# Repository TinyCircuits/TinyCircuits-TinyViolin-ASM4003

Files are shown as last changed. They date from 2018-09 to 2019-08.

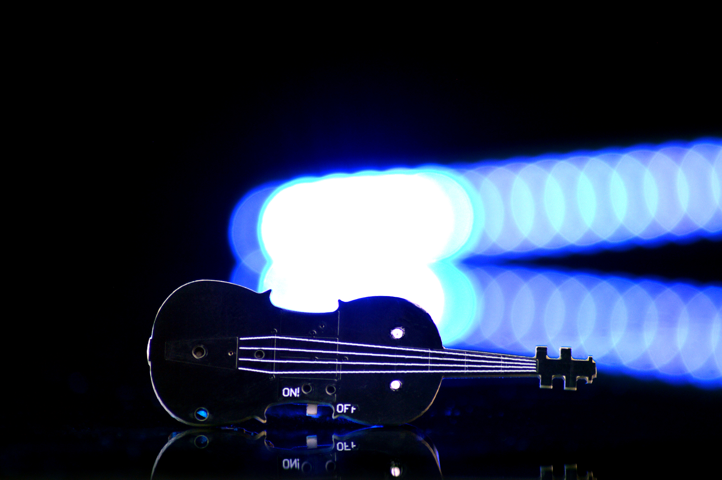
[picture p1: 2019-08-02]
images/ASM4003-Tutorial-Image-01.jpg

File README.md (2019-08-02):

# TinyCircuits TinyViolin
# ASM4003 Rev1

The design files are located under design_files/ for the TinyCircuits ASM4003 Rev 1 PCB.  This is a Tiny Violin with capacitive touch sensors and a buzzer.

Format is in Cadsoft Eagle format - Eagle version 6.2 was used for the original design.

For more infomation on this, check out the product page at TinyCircuits.com:  https://tinycircuits.com/collections/kits/products/tiny-violin

# License:

Design by TinyCircuits.
All design files are released under the Creative Commons Attribution Share-Alike 3.0 License, see the following link for details: http://creativecommons.org/licenses/by-sa/3.0

All text above must be included in any redistribution or derived design

This project uses designs and concepts developed as part of the Arduino project and the LilyPad project.  The TinyCircuits design files themselves (schematics, PCB and libraries) are not directly derived from these works' design files and have been created new, however the concepts and basic architecture behind the TinyDuino and TinyLily products are derived and we thank the hard work of the organizations below for their contributions to open-source hardware:
  
Original Arduino Uno Design by Team Arduino

LilyPad Arduino Design by Leah Buechley and Sparkfun Electronics

Please support the open-source hardware community

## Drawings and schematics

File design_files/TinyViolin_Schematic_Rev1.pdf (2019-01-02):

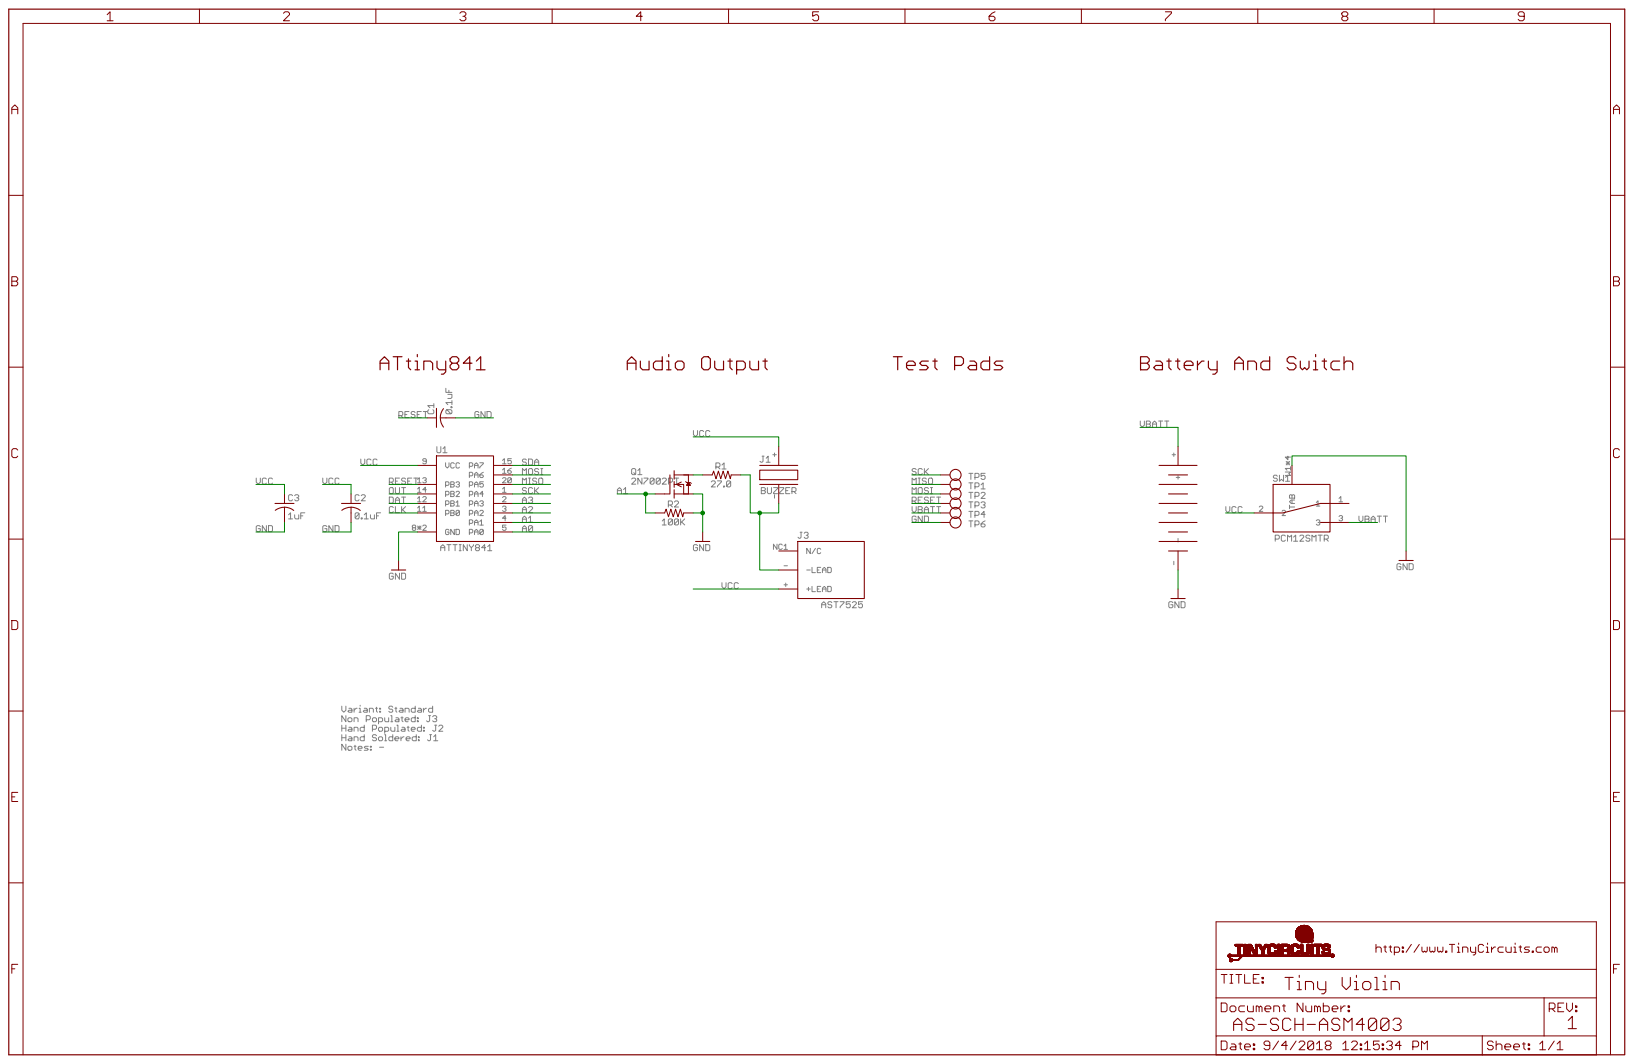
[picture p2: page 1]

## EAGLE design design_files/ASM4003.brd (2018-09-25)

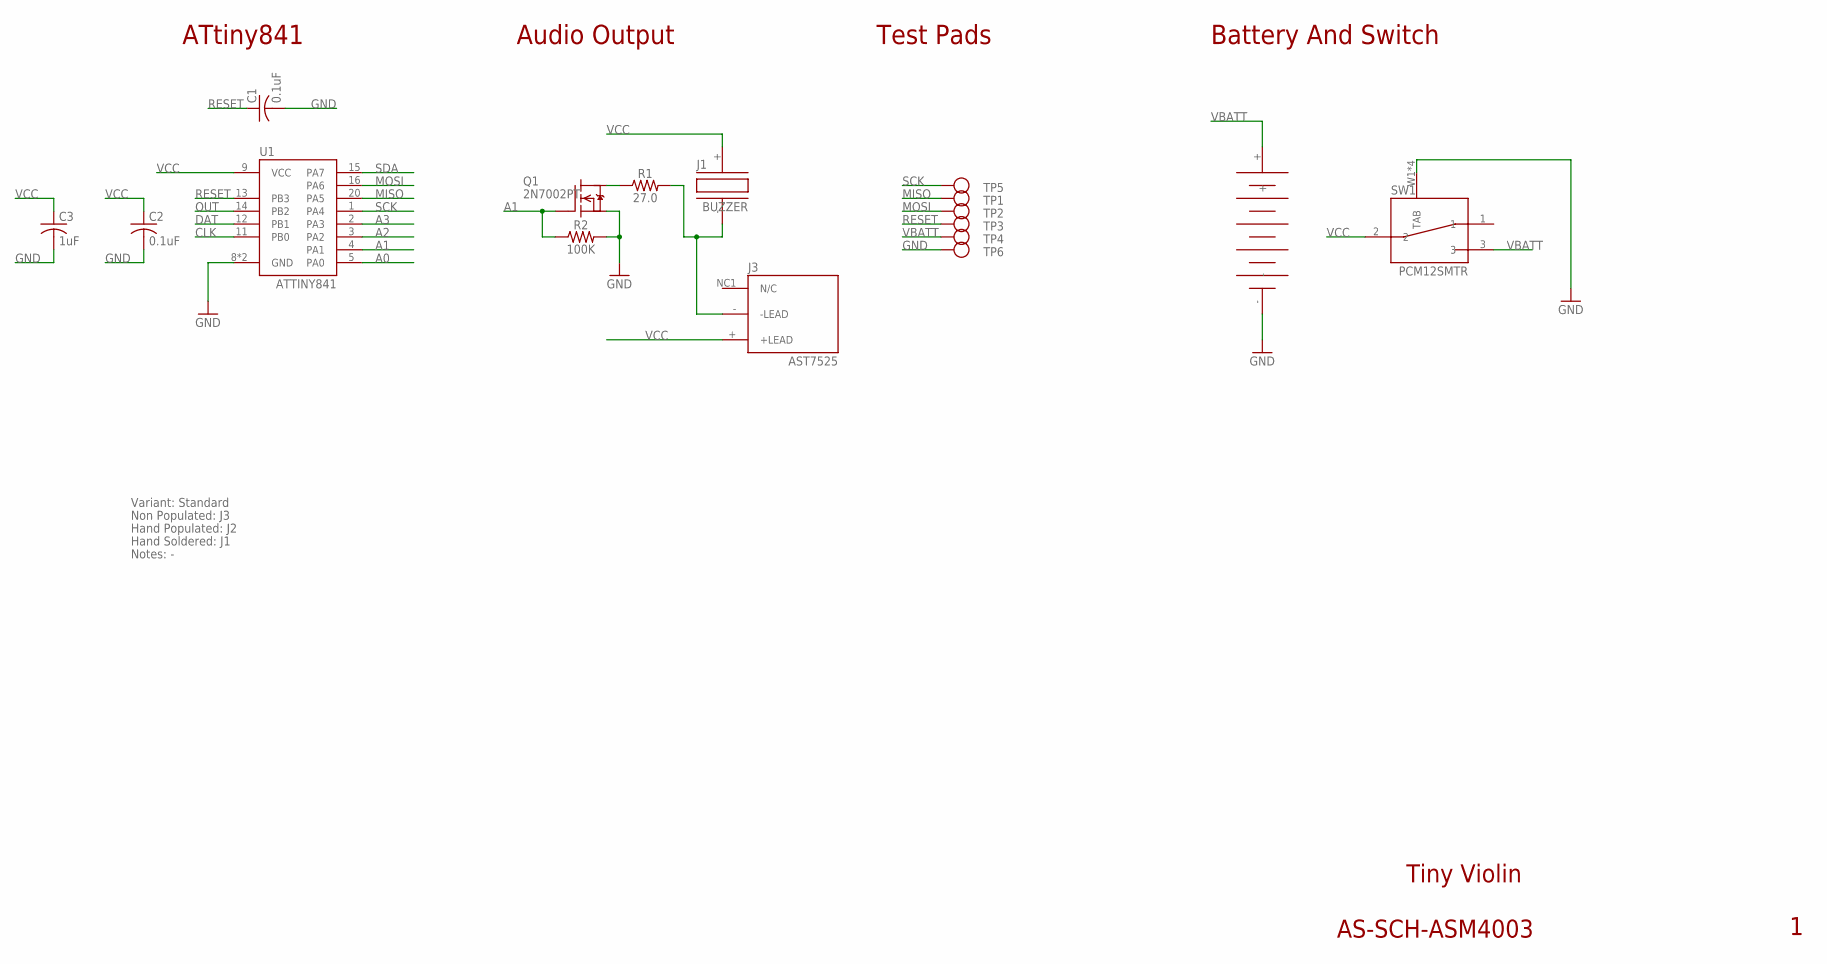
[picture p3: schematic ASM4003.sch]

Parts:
C1: 0.1uF; C0402; PARTNO AS-ITM-00008
C2: 0.1uF; C0402
C3: 1uF; C0402
J1: BUZZER; BUZZER_12MM
J2: 1225; COIN_1220_SMD; PARTNO AS-ITM-00468
J3: AST7525
Q1: 2N7002PT; SOT-416
R1: 27.0; 0402
R2: 100K; 0402
SW1: PCM12SMTR; PARTNO AS-ITM-00469
TP1, TP2, TP3, TP4, TP5, TP6: TEST_POINT; TEST_POINT_1MM
U1: ATTINY841; VQFN-20

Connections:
A0: U1.5 (PA0)
A1: Q1.1 (G), R2.1, U1.4 (PA1)
A2: U1.3 (PA2)
A3: U1.2 (PA3)
CLK: U1.11 (PB0)
DAT: U1.12 (PB1)
GND: C1.2, C2.2, C3.2, J2.-, Q1.2 (S), R2.2, SW1.W1 (TAB), SW1.W2 (TAB), SW1.W3 (TAB), SW1.W4 (TAB), TP6.P$1, U1.8 (GND), U1.PAD (GND)
MISO: TP1.P$1, U1.20 (PA5)
MOSI: TP2.P$1, U1.16 (PA6)
unnamed: Q1.3 (D), R1.1
unnamed: J1.- (2), J3.- (-LEAD), R1.2
OUT: U1.14 (PB2)
RESET: C1.1, TP3.P$1, U1.13 (PB3)
SCK: TP5.P$1, U1.1 (PA4)
SDA: U1.15 (PA7)
VBATT: J2.+, SW1.3, TP4.P$1
VCC: C2.1, C3.1, J1.+ (1), J3.+ (+LEAD), SW1.2, U1.9 (VCC)

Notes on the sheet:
Tiny Violin
AS-SCH-ASM4003
Test Pads
ATtiny841
Battery And Switch
Audio Output
Variant: Standard
Non Populated: J3
Hand Populated: J2
Hand Soldered: J1
Notes: -

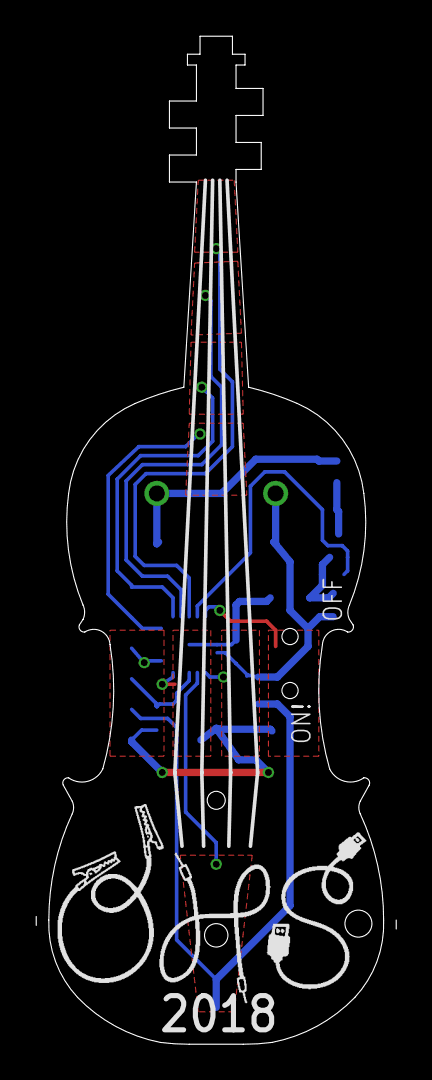
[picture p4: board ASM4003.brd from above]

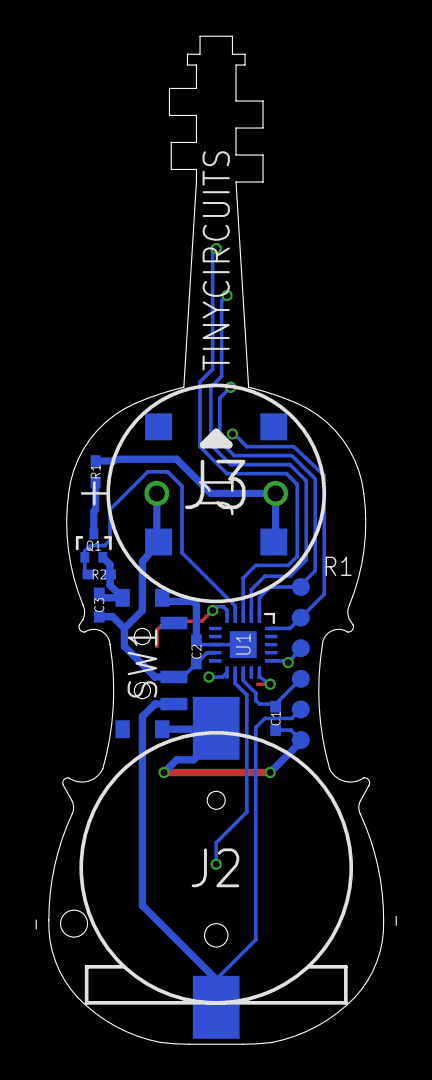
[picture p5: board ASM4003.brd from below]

Board: 2 copper layers, 20.0 x 56.0 mm, 18 parts (17 on the bottom side), 10 nets.

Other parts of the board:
U$1: DOCFIELD-TINYCIRCUITS-PCB

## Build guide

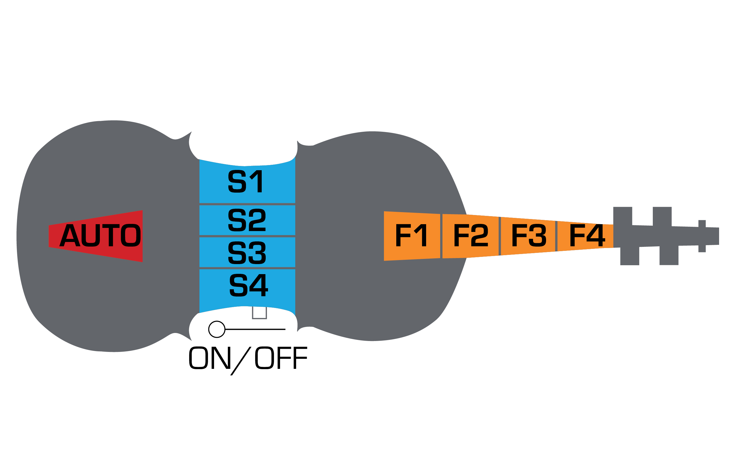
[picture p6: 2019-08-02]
images/ASM4003-Tutorial-Image-02.jpg

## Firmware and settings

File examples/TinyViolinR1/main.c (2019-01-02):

#include <inttypes.h>
#include <avr/io.h>
#include <avr/interrupt.h>
#include <util/delay.h>
#include <avr/sleep.h>
#include <avr/pgmspace.h>

#define true 1
#define false 0

int main(void);
unsigned int getCapReading(uint8_t pin);
unsigned int capRead(uint8_t pin);


uint8_t counter = 0;
uint8_t countMax = 30;
uint8_t buttonPressed = 0;
uint16_t capThresh = 535;

#define numCapChannels 9
int capTouchCal[numCapChannels];
int capTouchCurrent[numCapChannels];
int overCalCount[numCapChannels];
void play_RTTTL(const char* p);

unsigned long avg;
const int amtAvg = 5;
int avgBuf[5];
int avgPos = 0;

#include "pitches.h"
#include "songs.h"

uint16_t notesAll[7*5]={NOTE_C3,NOTE_D3,NOTE_E3,NOTE_F3,NOTE_G3,NOTE_A3, NOTE_B3,
                   NOTE_C4,NOTE_D4,NOTE_E4,NOTE_FS4,NOTE_G4,NOTE_A4, NOTE_B4,
                   NOTE_C5,NOTE_D5,NOTE_E5,NOTE_FS5,NOTE_G5,NOTE_A5, NOTE_B5,
                   NOTE_C6,NOTE_D6,NOTE_E6,NOTE_FS6,NOTE_G6,NOTE_A6, NOTE_B6,
                   NOTE_C7,NOTE_D7,NOTE_E7,NOTE_F7,NOTE_G7,NOTE_A7, NOTE_B7};

int maxReading = 0;
int primary = 0;
    
void updateCapTouch(){
    maxReading = 0;
    primary = 0;
    int j;
    for (j = 0; j < numCapChannels; j++) {
    int val = getCapReading(j);
    if (val < capTouchCal[j]) {
      capTouchCal[j] = val;
    } else if (val > capTouchCal[j] + 1) {
      overCalCount[j]++;
      if (overCalCount[j] > 3) {
        overCalCount[j] = 0;
        capTouchCal[j] += 1;
      } else {
        //overCalCount[j]=0;
      }
      
      if (j<9 && capTouchCurrent[j] > maxReading) {
        maxReading = capTouchCurrent[j];
        primary = j;
      }
    }
    capTouchCurrent[j] = val  - capTouchCal[j];
  }
}
int main(void) {
  int biggestMagnitude = 0;
  int isTouch = 0;
  int initialTouchPos = 0;
  int finalTouchPos = 0;
  int currentTouchedPositions = 0;

  CCP = 0xD8;
  CLKPR = 0;

  
  DDRA=(1<<1);
  ADCSRA = _BV(ADEN) | 4 | 1;//250KHz clock

  int pin, i, j;
  for (pin = 0; pin < numCapChannels; pin++) {
    capTouchCal[pin] = 1000;//getCapReading(pin);
    overCalCount[pin] = 0;
  }
  
  TOCPMSA0 = _BV(TOCC0S1);
  TCCR2A = _BV(COM2A1)|_BV(COM2B1)|_BV(WGM21);
  TCCR2B = _BV(WGM23)|_BV(WGM22)|_BV(CS20);
  //TIFR2 = _BV(TOV2);
  //31250
  uint8_t pulseWidth=128;
  
  ICR2 = 255-1;
  
    if(pulseWidth){
      OCR2B=pulseWidth-1;
      TOCPMCOE|=((1<<TOCC0OE));
    }else{
      TOCPMCOE&=~((1<<TOCC0OE));
      OCR2B=0;
    }
    
  
  while (1)
  {
    _delay_ms(10);
  
    updateCapTouch();
    
    int ledToLight = primary*3;
    if (primary < 5)
      ledToLight += (capTouchCurrent[primary + 1] / (maxReading/2));
    if (primary > 0)
      ledToLight -= (capTouchCurrent[primary - 1] / (maxReading/2));
      
    int completedTouch = 0;
    int onSwipe = 0;
    int offSwipe = 0;
      
    uint16_t tone=0;
    
    int s1=capTouchCurrent[5];int s1v=30;
    int s2=capTouchCurrent[6];int s2v=85;
    int s3=capTouchCurrent[7];int s3v=12;
    int s4=capTouchCurrent[0];int s4v=40;
      
    if(s1>s1v && s1-s1v>s2-s2v){
      tone=4;
    }
    if(s4>s4v && s4-s4v>s3-s3v){
      tone=14+2;
    }
    if(s3>s3v && s3-s3v>=s2-s2v){// s3-s3v>=s4-s4v && 
      tone=7+5;
    }
    if(s2>s2v && s2-s2v>=s3-s3v){// && s2-s2v>=s1-s1v
      tone=7+1;
    }
    
    if(tone){
      if(capTouchCurrent[4]>100 && capTouchCurrent[3]>110/2){
        tone+=4;
      }
      else if(capTouchCurrent[3]>110){
        tone+=3;
      }
      else if(capTouchCurrent[2]>110){
        tone+=2;
      }
      else if(capTouchCurrent[1]>100){
        tone+=1;
      }
    }
    if(!tone){
      if(capTouchCurrent[8]>150){
        TOCPMCOE|=((1<<TOCC0OE));
          
          unsigned int rand=0;
          for (j = 0; j < numCapChannels; j++) {
            rand+=capTouchCurrent[j]+capTouchCal[j];
          }
          while(rand>9)rand-=9;
          if(rand==0){
            play_RTTTL(song_0);
          }else if(rand==1){
            play_RTTTL(song_1);
          }else if(rand==2){
            play_RTTTL(song_2);
          }else if(rand==3){
            play_RTTTL(song_3);
          }else if(rand==4){
            play_RTTTL(song_4);
          }else if(rand==5){
            play_RTTTL(song_5);
          }else if(rand==6){
            play_RTTTL(song_6);
          }else if(rand==7){
            play_RTTTL(song_7);
          }else if(rand==8){
            play_RTTTL(song_8);
          }else if(rand==9){
            play_RTTTL(song_9);
          }
      }
    }
    if(tone){
      tone=8000000ul/(unsigned long)notesAll[tone];
      if(ICR2!=tone){
        ICR2=tone;
        OCR2B=tone/2;
        TOCPMCOE|=((1<<TOCC0OE));
        }
      if (!isTouch) {
        isTouch = 1;
        initialTouchPos = primary;
        finalTouchPos = primary;
        currentTouchedPositions=0;
      } else {
        finalTouchPos = primary;
        for (j = 0; j < 6; j++) {
          if(capTouchCurrent[j]>10)
            currentTouchedPositions|=(1<<j);
         }
      }
    } /*else {
      if (isTouch) {
        isTouch = 0;
        completedTouch = 1;
      }
    }*/else{
      if(ICR2!=0){
        TOCPMCOE&=~((1<<TOCC0OE));
        ICR2=0;
        PORTA=0;
        }
    }
    
  }
  return 0;
}

unsigned int getCapReading(uint8_t pin) {
  unsigned int i, avg=0;
  for (i = 0; i < 10; i++) {
    avg += capRead(pin);
  }
  avg /= 10;
  return avg;
}

unsigned int capRead(uint8_t pin) {
  while(PINA&(1<<1));
  _delay_us(1);
  if(pin>0)pin+=1;
  
  if(pin==8){
    pin=11;
    PUEB |= (1 << (0)); //charge external cap
  }else if(pin==9){
    pin=10;
    PUEB |= (1 << (1)); //charge external cap
  }else{
    PUEA |= (1 << pin); //charge external cap
  }

  ADMUXA = 0x0E; //connect ADC input cap to GND
  ADCSRA |= _BV(ADSC); //run ADC
  while (ADCSRA & _BV(ADSC));
  
  if(pin==10){
    PUEB &= ~(1 << (1)); //float external cap
  }else if(pin==11){
    PUEB &= ~(1 << (0)); //float external cap
  }else{
    PUEA &= ~(1 << pin); //float external cap
  }
  

  ADMUXA = (pin) & 0x0F; //connect ADC cap to external cap
  ADCSRA |= _BV(ADSC); //run ADC
  while (ADCSRA & _BV(ADSC));

  unsigned int result = ADCL; //result is proportional to external/internal
  return (ADCH << 8) | result;
}
#define byte uint8_t
#define OCTAVE_OFFSET 0


int tone_pin = 6;
volatile uint32_t count = 0;
int prev = 0;

void delay(int dcount){
  int c=0;
  for(;c<dcount;c++){
    _delay_us(999);
  }
}

void tone(int pin, int note)
{
  uint16_t val = 8000000ul/(unsigned long)note;
  ICR2 = val;
  OCR2B = val/2;

}
 
 void noTone(int pin){
 
  ICR2 = 0;
  OCR2B = 0;
 
 
 }
 

#define isdigit(n) (n >= '0' && n <= '9')


void play_RTTTL(const char* p){
 
  byte default_dur = 4;
  byte default_oct = 6;
  int bpm = 63;
  int num;
  long wholenote;
  long duration;
  byte note;
  byte scale;
 
   // Absolutely no error checking in here


  // format: d=N,o=N,b=NNN:
  // find the start (skip name, etc)

  while(pgm_read_byte(p) != ':')p++; // ignore name
  p++;                     // skip ':'

  // get default duration
  if(pgm_read_byte(p) == 'd')
  {
    p++; p++;              // skip "d="
    num = 0;
    while(isdigit(pgm_read_byte(p)))
    {
      num = (num * 10) + (pgm_read_byte(p) - '0');
      p++;
    }
    if(num > 0) default_dur = num;
    p++;                   // skip comma
  }

  // get default octave
  if(pgm_read_byte(p) == 'o')
  {
    p++; p++;              // skip "o="
    num = pgm_read_byte(p) - '0';
    p++;
    if(num >= 3 && num <=7) default_oct = num;
    p++;                   // skip comma
  }

  // get BPM
  if(pgm_read_byte(p) == 'b')
  {
    p++; p++;              // skip "b="
    num = 0;
    while(isdigit(pgm_read_byte(p)))
    {
      num = (num * 10) + (pgm_read_byte(p) - '0');
      p++;
    }
    bpm = num;
    p++;                   // skip colon
  }

  // BPM usually expresses the number of quarter notes per minute
  wholenote = (60 * 1000L / bpm) * 4;  // this is the time for whole note (in milliseconds)


  // now begin note loop
  while(pgm_read_byte(p))
  {
    // first, get note duration, if available
    num = 0;
    while(isdigit(pgm_read_byte(p)))
    {
      num = (num * 10) + (pgm_read_byte(p) - '0');
      p++;
    }
    
    if(num) duration = wholenote / num;
    else duration = wholenote / default_dur;  // we will need to check if we are a dotted note after

    // now get the note
    note = 0;

    switch(pgm_read_byte(p))
    {
      case 'c':
        note = 1;
        break;
      case 'd':
        note = 3;
        break;
      case 'e':
        note = 5;
        break;
      case 'f':
        note = 6;
        break;
      case 'g':
        note = 8;
        break;
      case 'a':
        note = 10;
        break;
      case 'b':
        note = 12;
        break;
      case 'p':
      default:
        note = 0;
    }
    p++;

    // now, get optional '#' sharp
    if(pgm_read_byte(p) == '#')
    {
      note++;
      p++;
    }

    // now, get optional '.' dotted note
    if(pgm_read_byte(p) == '.')
    {
      duration += duration/2;
      p++;
    }
  
    // now, get scale
    if(isdigit(pgm_read_byte(p)))
    {
      scale = pgm_read_byte(p) - '0';
      p++;
    }
    else
    {
      scale = default_oct;
    }

    scale += OCTAVE_OFFSET;

    if(pgm_read_byte(p) == ',')
      p++;       // skip comma for next note (or we may be at the end)

    // now play the note

    if(note)
    {
      tone(tone_pin, notes[(scale - 4) * 12 + note]); // original - 4, not - 5 
      delay(duration);
      noTone(tone_pin);
    }
    else
    {
      delay(duration);
    }
  }
}
 
